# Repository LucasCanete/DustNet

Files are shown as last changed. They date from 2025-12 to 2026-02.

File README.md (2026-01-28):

# DustNet
Dust Measuring Station - Hochschule Osnabrück/Metropolia University

## Board Features

- Dual-socket for Polverine and DFR1117 (mutually excl.)
- LiPo Protection Circuit
- 5V Power
- MPPT for charging
- USB-C for charging
- BME690 footprint (I2C)
- BMV080 connector (I2C)
- SPS30 connector (I2C)

## BOM

TBD

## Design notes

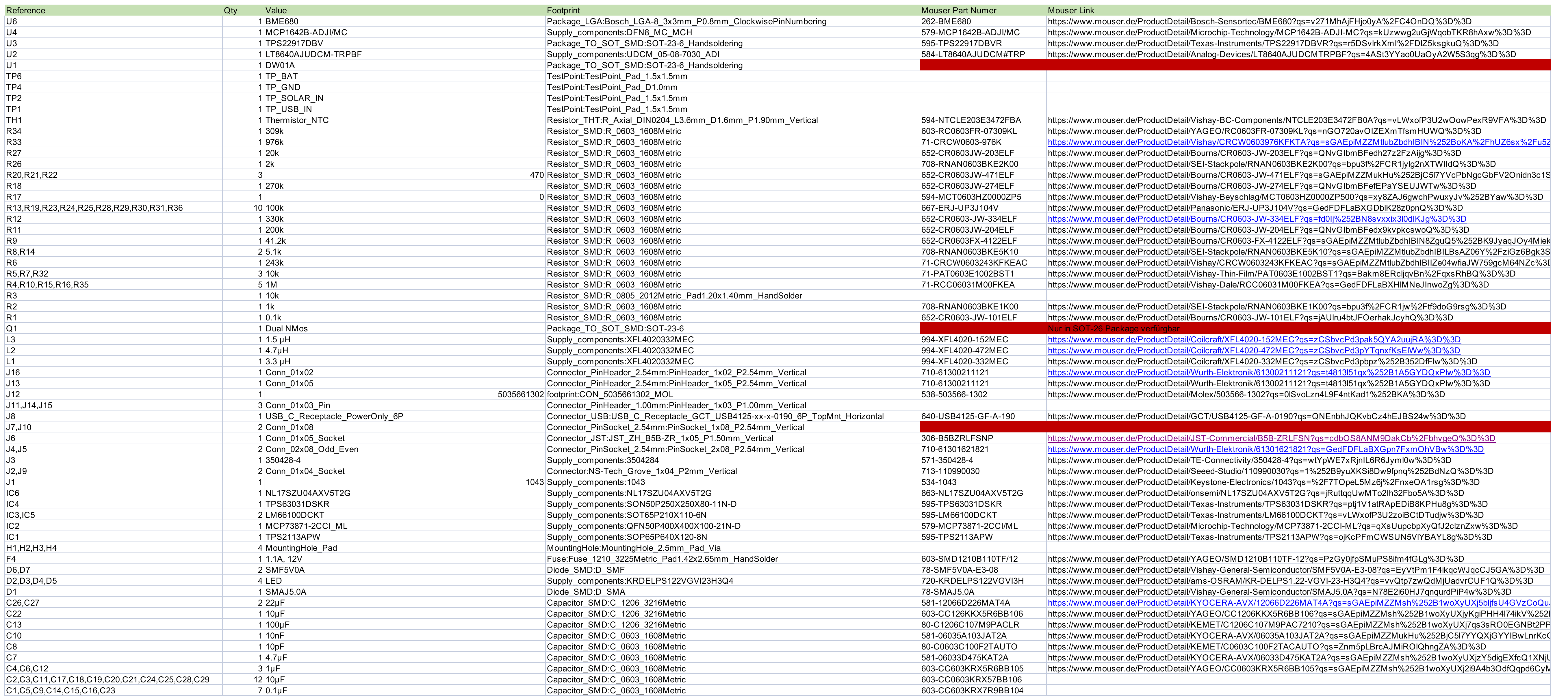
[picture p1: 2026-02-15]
isd-board_polverine_v2/isd-board_polverine.png

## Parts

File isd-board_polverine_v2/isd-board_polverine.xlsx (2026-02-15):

Reference | Qty | Value | Footprint | Mouser Part Numer | Mouser Link
U6 | 1 | BME680 | Package_LGA:Bosch_LGA-8_3x3mm_P0.8mm_ClockwisePinNumbering | 262-BME680 | https://www.mouser.de/ProductDetail/Bosch-Sensortec/BME680?qs=v271MhAjFHjo0yA%2FC4OnDQ%3D%3D
U4 | 1 | MCP1642B-ADJI/MC | Supply_components:DFN8_MC_MCH | 579-MCP1642B-ADJI/MC | https://www.mouser.de/ProductDetail/Microchip-Technology/MCP1642B-ADJI-MC?qs=kUzwwg2uGjWqobTKR8hAxw%3D%3D
U3 | 1 | TPS22917DBV | Package_TO_SOT_SMD:SOT-23-6_Handsoldering | 595-TPS22917DBVR | https://www.mouser.de/ProductDetail/Texas-Instruments/TPS22917DBVR?qs=r5DSvlrkXmI%2FDlZ5ksgkuQ%3D%3D
U2 | 1 | LT8640AJUDCM-TRPBF | Supply_components:UDCM_05-08-7030_ADI | 584-LT8640AJUDCM#TRP | https://www.mouser.de/ProductDetail/Analog-Devices/LT8640AJUDCMTRPBF?qs=4ASt3YYao0UaOyA2W5S3qg%3D%3D
U1 | 1 | DW01A | Package_TO_SOT_SMD:SOT-23-6_Handsoldering
TP6 | 1 | TP_BAT | TestPoint:TestPoint_Pad_1.5x1.5mm
TP4 | 1 | TP_GND | TestPoint:TestPoint_Pad_D1.0mm
TP2 | 1 | TP_SOLAR_IN | TestPoint:TestPoint_Pad_1.5x1.5mm
TP1 | 1 | TP_USB_IN | TestPoint:TestPoint_Pad_1.5x1.5mm
TH1 | 1 | Thermistor_NTC | Resistor_THT:R_Axial_DIN0204_L3.6mm_D1.6mm_P1.90mm_Vertical | 594-NTCLE203E3472FBA | https://www.mouser.de/ProductDetail/Vishay-BC-Components/NTCLE203E3472FB0A?qs=vLWxofP3U2wOowPexR9VFA%3D%3D
R34 | 1 | 309k | Resistor_SMD:R_0603_1608Metric | 603-RC0603FR-07309KL | https://www.mouser.de/ProductDetail/YAGEO/RC0603FR-07309KL?qs=nGO720avOIZEXmTfsmHUWQ%3D%3D
R33 | 1 | 976k | Resistor_SMD:R_0603_1608Metric | 71-CRCW0603-976K | https://www.mouser.de/ProductDetail/Vishay/CRCW0603976KFKTA
R27 | 1 | 20k | Resistor_SMD:R_0603_1608Metric | 652-CR0603JW-203ELF | https://www.mouser.de/ProductDetail/Bourns/CR0603-JW-203ELF?qs=QNvGIbmBFedh27z2FzAijg%3D%3D
R26 | 1 | 2k | Resistor_SMD:R_0603_1608Metric | 708-RNAN0603BKE2K00 | https://www.mouser.de/ProductDetail/SEI-Stackpole/RNAN0603BKE2K00?qs=bpu3f%2FCR1jylg2nXTWIIdQ%3D%3D
R20,R21,R22 | 3 | 470 | Resistor_SMD:R_0603_1608Metric | 652-CR0603JW-471ELF | https://www.mouser.de/ProductDetail/Bourns/CR0603-JW-471ELF
R18 | 1 | 270k | Resistor_SMD:R_0603_1608Metric | 652-CR0603JW-274ELF | https://www.mouser.de/ProductDetail/Bourns/CR0603-JW-274ELF?qs=QNvGIbmBFefEPaYSEUJWTw%3D%3D
R17 | 1 | 0 | Resistor_SMD:R_0603_1608Metric | 594-MCT0603HZ0000ZP5 | https://www.mouser.de/ProductDetail/Vishay-Beyschlag/MCT0603HZ0000ZP500?qs=xy8ZAJ6gwchPwuxyJv%252BYaw%3D%3D
R13,R19,R23,R24,R25,R28,R29,R30,R31,R36 | 10 | 100k | Resistor_SMD:R_0603_1608Metric | 667-ERJ-UP3J104V | https://www.mouser.de/ProductDetail/Panasonic/ERJ-UP3J104V?qs=GedFDFLaBXGDblK28z0pnQ%3D%3D
R12 | 1 | 330k | Resistor_SMD:R_0603_1608Metric | 652-CR0603-JW-334ELF | https://www.mouser.de/ProductDetail/Bourns/CR0603-JW-334ELF?qs=fd0Ij%252BN8svxxix3l0dIKJg%3D%3D
R11 | 1 | 200k | Resistor_SMD:R_0603_1608Metric | 652-CR0603JW-204ELF | https://www.mouser.de/ProductDetail/Bourns/CR0603-JW-204ELF?qs=QNvGIbmBFedx9kvpkcswoQ%3D%3D
R9 | 1 | 41.2k | Resistor_SMD:R_0603_1608Metric | 652-CR0603FX-4122ELF | https://www.mouser.de/ProductDetail/Bourns/CR0603-FX-4122ELF
R8,R14 | 2 | 5.1k | Resistor_SMD:R_0603_1608Metric | 708-RNAN0603BKE5K10 | https://www.mouser.de/ProductDetail/SEI-Stackpole/RNAN0603BKE5K10
R6 | 1 | 243k | Resistor_SMD:R_0603_1608Metric | 71-CRCW0603243KFKEAC | https://www.mouser.de/ProductDetail/Vishay/CRCW0603243KFKEAC?qs=sGAEpiMZZMtlubZbdhIBIIZe04wfiaJW759gcM64NZc%3D
R5,R7,R32 | 3 | 10k | Resistor_SMD:R_0603_1608Metric | 71-PAT0603E1002BST1 | https://www.mouser.de/ProductDetail/Vishay-Thin-Film/PAT0603E1002BST1?qs=Bakm8ERcljqvBn%2FqxsRhBQ%3D%3D
R4,R10,R15,R16,R35 | 5 | 1M | Resistor_SMD:R_0603_1608Metric | 71-RCC06031M00FKEA | https://www.mouser.de/ProductDetail/Vishay-Dale/RCC06031M00FKEA?qs=GedFDFLaBXHlMNeJInwoZg%3D%3D
R3 | 1 | 10k | Resistor_SMD:R_0805_2012Metric_Pad1.20x1.40mm_HandSolder
R2 | 1 | 1k | Resistor_SMD:R_0603_1608Metric | 708-RNAN0603BKE1K00 | https://www.mouser.de/ProductDetail/SEI-Stackpole/RNAN0603BKE1K00?qs=bpu3f%2FCR1jw%2Ftf9doG9rsg%3D%3D
R1 | 1 | 0.1k | Resistor_SMD:R_0603_1608Metric | 652-CR0603-JW-101ELF | https://www.mouser.de/ProductDetail/Bourns/CR0603-JW-101ELF?qs=jAUlru4btJFOerhakJcyhQ%3D%3D
Q1 | 1 | Dual NMos | Package_TO_SOT_SMD:SOT-23-6 |  | Nur in SOT-26 Package verfürgbar
L3 | 1 | 1.5 µH | Supply_components:XFL4020332MEC | 994-XFL4020-152MEC | https://www.mouser.de/ProductDetail/Coilcraft/XFL4020-152MEC?qs=zCSbvcPd3pak5QYA2uujRA%3D%3D
L2 | 1 | 4.7µH | Supply_components:XFL4020332MEC | 994-XFL4020-472MEC | https://www.mouser.de/ProductDetail/Coilcraft/XFL4020-472MEC?qs=zCSbvcPd3pYTqnxfKsElWw%3D%3D
L1 | 1 | 3.3 µH | Supply_components:XFL4020332MEC | 994-XFL4020-332MEC | https://www.mouser.de/ProductDetail/Coilcraft/XFL4020-332MEC?qs=zCSbvcPd3pbpz%252B352DfFlw%3D%3D
J16 | 1 | Conn_01x02 | Connector_PinHeader_2.54mm:PinHeader_1x02_P2.54mm_Vertical | 710-61300211121 | https://www.mouser.de/ProductDetail/Wurth-Elektronik/61300211121?qs=t4813l51qx%252B1A5GYDQxPlw%3D%3D
J13 | 1 | Conn_01x05 | Connector_PinHeader_2.54mm:PinHeader_1x05_P2.54mm_Vertical | 710-61300211121 | https://www.mouser.de/ProductDetail/Wurth-Elektronik/61300211121?qs=t4813l51qx%252B1A5GYDQxPlw%3D%3D
J12 | 1 | 5035661302 | footprint:CON_5035661302_MOL | 538-503566-1302 | https://www.mouser.de/ProductDetail/Molex/503566-1302?qs=0lSvoLzn4L9F4ntKad1%252BKA%3D%3D
J11,J14,J15 | 3 | Conn_01x03_Pin | Connector_PinHeader_1.00mm:PinHeader_1x03_P1.00mm_Vertical
J8 | 1 | USB_C_Receptacle_PowerOnly_6P | Connector_USB:USB_C_Receptacle_GCT_USB4125-xx-x-0190_6P_TopMnt_Horizontal | 640-USB4125-GF-A-190 | https://www.mouser.de/ProductDetail/GCT/USB4125-GF-A-0190?qs=QNEnbhJQKvbCz4hEJBS24w%3D%3D
J7,J10 | 2 | Conn_01x08 | Connector_PinSocket_2.54mm:PinSocket_1x08_P2.54mm_Vertical
J6 | 1 | Conn_01x05_Socket | Connector_JST:JST_ZH_B5B-ZR_1x05_P1.50mm_Vertical | 306-B5BZRLFSNP | https://www.mouser.de/ProductDetail/JST-Commercial/B5B-ZRLFSN?qs=cdbOS8ANM9DakCb%2FbhvgeQ%3D%3D
J4,J5 | 2 | Conn_02x08_Odd_Even | Connector_PinSocket_2.54mm:PinSocket_2x08_P2.54mm_Vertical | 710-61301621821 | https://www.mouser.de/ProductDetail/Wurth-Elektronik/61301621821?qs=GedFDFLaBXGpn7FxmOhVBw%3D%3D
J3 | 1 | 350428-4 | Supply_components:3504284 | 571-350428-4 | https://www.mouser.de/ProductDetail/TE-Connectivity/350428-4?qs=wtYpWE7xRjnIL6R6Jyml0w%3D%3D
J2,J9 | 2 | Conn_01x04_Socket | Connector:NS-Tech_Grove_1x04_P2mm_Vertical | 713-110990030 | https://www.mouser.de/ProductDetail/Seeed-Studio/110990030?qs=1%252B9yuXKSi8Dw9fpnq%252BdNzQ%3D%3D
J1 | 1 | 1043 | Supply_components:1043 | 534-1043 | https://www.mouser.de/ProductDetail/Keystone-Electronics/1043?qs=%2F7TOpeL5Mz6j%2FnxeOA1rsg%3D%3D
IC6 | 1 | NL17SZU04AXV5T2G | Supply_components:NL17SZU04AXV5T2G | 863-NL17SZU04AXV5T2G | https://www.mouser.de/ProductDetail/onsemi/NL17SZU04AXV5T2G?qs=jRuttqqUwMTo2Ih32Fbo5A%3D%3D
IC4 | 1 | TPS63031DSKR | Supply_components:SON50P250X250X80-11N-D | 595-TPS63031DSKR | https://www.mouser.de/ProductDetail/Texas-Instruments/TPS63031DSKR?qs=ptj1V1atRApEDiB8KPHu8g%3D%3D
IC3,IC5 | 2 | LM66100DCKT | Supply_components:SOT65P210X110-6N | 595-LM66100DCKT | https://www.mouser.de/ProductDetail/Texas-Instruments/LM66100DCKT?qs=vLWxofP3U2zoiBCtDTudjw%3D%3D
IC2 | 1 | MCP73871-2CCI_ML | Supply_components:QFN50P400X400X100-21N-D | 579-MCP73871-2CCI/ML | https://www.mouser.de/ProductDetail/Microchip-Technology/MCP73871-2CCI-ML?qs=qXsUupcbpXyQfJ2clznZxw%3D%3D
IC1 | 1 | TPS2113APW | Supply_components:SOP65P640X120-8N | 595-TPS2113APW | https://www.mouser.de/ProductDetail/Texas-Instruments/TPS2113APW?qs=ojKcPFmCWSUN5VlYBAYL8g%3D%3D
H1,H2,H3,H4 | 4 | MountingHole_Pad | MountingHole:MountingHole_2.5mm_Pad_Via
F4 | 1 | 1.1A, 12V | Fuse:Fuse_1210_3225Metric_Pad1.42x2.65mm_HandSolder | 603-SMD1210B110TF/12 | https://www.mouser.de/ProductDetail/YAGEO/SMD1210B110TF-12?qs=PzGy0jfpSMuPS8ifm4fGLg%3D%3D
D6,D7 | 2 | SMF5V0A | Diode_SMD:D_SMF | 78-SMF5V0A-E3-08 | https://www.mouser.de/ProductDetail/Vishay-General-Semiconductor/SMF5V0A-E3-08?qs=EyVtPm1F4ikqcWJqcCJ5GA%3D%3D
D2,D3,D4,D5 | 4 | LED | Supply_components:KRDELPS122VGVI23H3Q4 | 720-KRDELPS122VGVI3H | https://www.mouser.de/ProductDetail/ams-OSRAM/KR-DELPS1.22-VGVI-23-H3Q4?qs=vvQtp7zwQdMjUadvrCUF1Q%3D%3D
D1 | 1 | SMAJ5.0A | Diode_SMD:D_SMA | 78-SMAJ5.0A | https://www.mouser.de/ProductDetail/Vishay-General-Semiconductor/SMAJ5.0A?qs=N78E2i60HJ7qnqurdPiP4w%3D%3D
C26,C27 | 2 | 22µF | Capacitor_SMD:C_1206_3216Metric | 581-12066D226MAT4A | https://www.mouser.de/ProductDetail/KYOCERA-AVX/12066D226MAT4A
C22 | 1 | 10µF | Capacitor_SMD:C_1206_3216Metric | 603-CC126KKX5R6BB106 | https://www.mouser.de/ProductDetail/YAGEO/CC1206KKX5R6BB106
C13 | 1 | 100µF | Capacitor_SMD:C_1206_3216Metric | 80-C1206C107M9PACLR | https://www.mouser.de/ProductDetail/KEMET/C1206C107M9PAC7210
C10 | 1 | 10nF | Capacitor_SMD:C_0603_1608Metric | 581-06035A103JAT2A | https://www.mouser.de/ProductDetail/KYOCERA-AVX/06035A103JAT2A
C8 | 1 | 10pF | Capacitor_SMD:C_0603_1608Metric | 80-C0603C100F2TAUTO | https://www.mouser.de/ProductDetail/KEMET/C0603C100F2TACAUTO?qs=Znm5pLBrcAJMiROlQhngZA%3D%3D
C7 | 1 | 4.7µF | Capacitor_SMD:C_0603_1608Metric | 581-06033D475KAT2A | https://www.mouser.de/ProductDetail/KYOCERA-AVX/06033D475KAT2A
C4,C6,C12 | 3 | 1µF | Capacitor_SMD:C_0603_1608Metric | 603-CC603KRX5R6BB105 | https://www.mouser.de/ProductDetail/YAGEO/CC0603KRX5R6BB105
C2,C3,C11,C17,C18,C19,C20,C21,C24,C25,C28,C29 | 12 | 10µF | Capacitor_SMD:C_0603_1608Metric | 603-CC0603KRX57BB106
C1,C5,C9,C14,C15,C16,C23 | 7 | 0.1µF | Capacitor_SMD:C_0603_1608Metric | 603-CC603KRX7R9BB104

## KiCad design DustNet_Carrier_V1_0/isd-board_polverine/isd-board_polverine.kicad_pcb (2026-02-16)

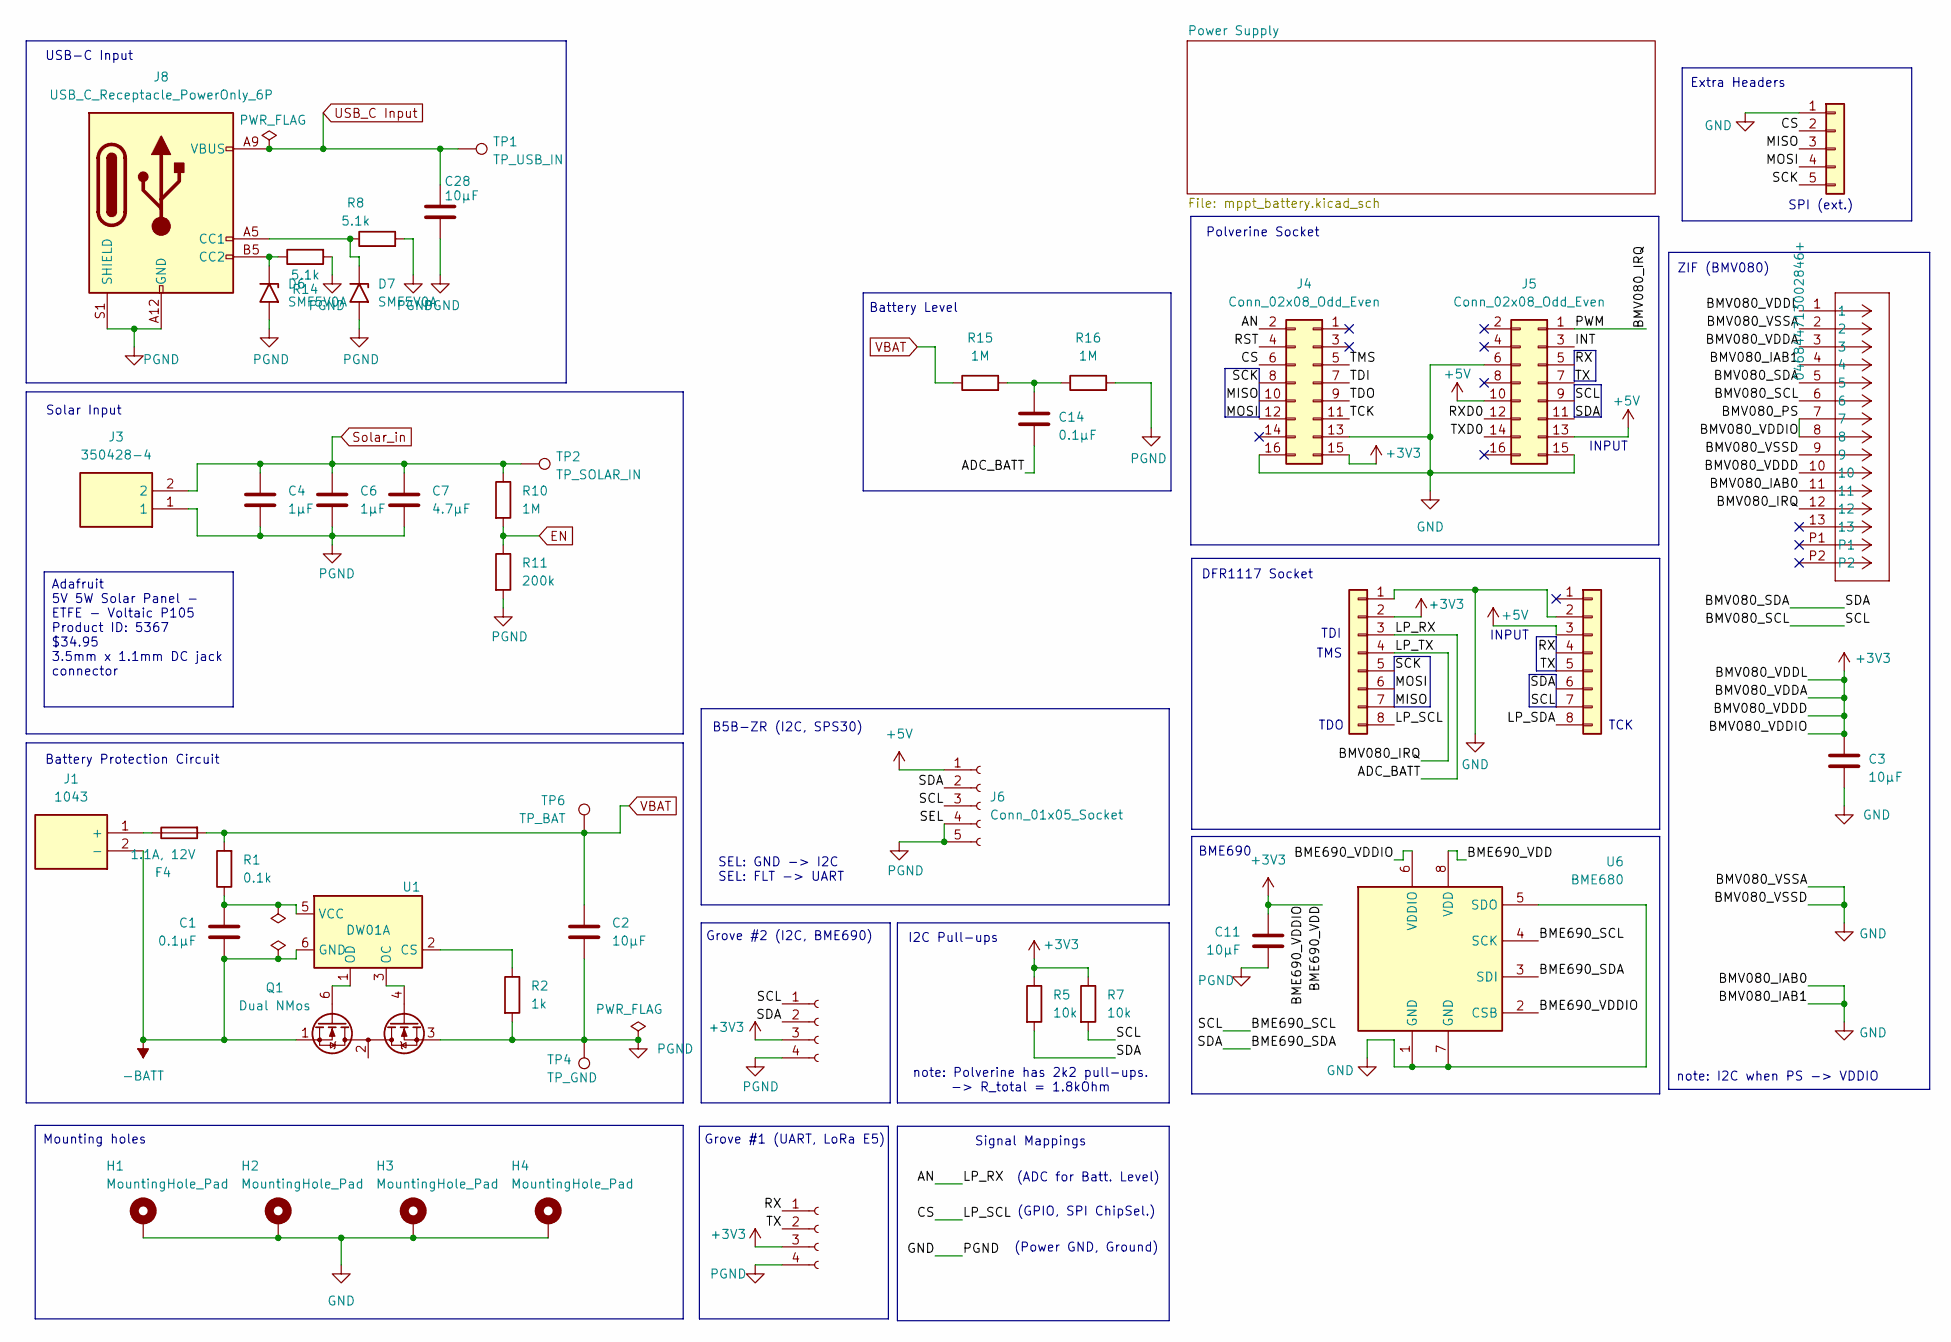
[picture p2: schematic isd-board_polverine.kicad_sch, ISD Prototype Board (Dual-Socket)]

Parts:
C1, C14: 0.1µF; C_0603_1608Metric; MPN 399-C0805C104K5RACTUCT-ND
C2, C3, C11: 10µF; C_0603_1608Metric; MPN GRM21BR61E106KA73K
C4, C6: 1µF; C_0603_1608Metric
C7: 4.7µF; C_0603_1608Metric
C28: 10µF; C_0603_1608Metric
D6, D7: SMF5V0A; D_SMF
F4: 1.1A, 12V; Fuse_1210_3225Metric_Pad1.42x2.65mm_HandSolder; MPN SMD1210B110TF
H1, H2, H3, H4: MountingHole_Pad; MountingHole_2.5mm_Pad_Via; MPN none
J1: 1043; Mouser Part Number 534-1043
J2, J9: Conn_01x04_Socket; NS-Tech_Grove_1x04_P2mm_Vertical; MPN 1597-1082-ND
J3: 350428-4; 3504284; Mouser Part Number 571-350428-4
J4, J5: Conn_02x08_Odd_Even; PinSocket_2x08_P2.54mm_Vertical; MPN 732-61301621821-ND
J6: Conn_01x05_Socket; JST_ZH_B5B-ZR_1x05_P1.50mm_Vertical; MPN B5B-ZR
J7, J10: Conn_01x08; PinSocket_1x08_P2.54mm_Vertical; MPN PPTC081LFBN-RC
J8: USB_C_Receptacle_PowerOnly_6P; USB_C_Receptacle_GCT_USB4125-xx-x-0190_6P_TopMnt_Horizontal; MPN USB4125-GF-A
J12: 5035661302; CON_5035661302_MOL; MPN 046844713002846+
J13: Conn_01x05; PinHeader_1x05_P2.54mm_Vertical; MPN ???
Q1: Dual NMos; SOT-23-6; MPN DMG9926UDMDICT-ND
R1: 0.1k; R_0603_1608Metric; MPN 541-100CCT-ND
R2: 1k; R_0603_1608Metric; MPN 10-ERJ-HP6J102VCT-ND
R5, R7: 10k; R_0603_1608Metric; MPN 541-4163-1-ND
R8, R14: 5.1k; R_0603_1608Metric; MPN 311-5.1KARCT-ND
R10: 1M; R_0603_1608Metric
R11: 200k; R_0603_1608Metric
R15, R16: 1M; R_0603_1608Metric; MPN 408-RG2012P-105-B-T5CT-ND
TP1: TP_USB_IN; TestPoint_Pad_1.5x1.5mm; MPN none
TP2: TP_SOLAR_IN; TestPoint_Pad_1.5x1.5mm; MPN none
TP4: TP_GND; TestPoint_Pad_D1.0mm; MPN none
TP6: TP_BAT; TestPoint_Pad_1.5x1.5mm; MPN none
U1: DW01A; SOT-23-6_Handsoldering; MPN DW01A
U6: BME680; Bosch_LGA-8_3x3mm_P0.8mm_ClockwisePinNumbering; MPN BME690

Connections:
+3V3: C3.1, C11.1, J2.3, J4.15, J9.3, J10.2, J12.1, J12.3, J12.7, J12.8, J12.10, R5.1, R7.1, U6.2 (CSB), U6.6 (VDDIO), U6.8 (VDD); also elsewhere on the board
+5V: J5.10, J5.13, J6.1, J7.3; also elsewhere on the board
-BATT: C1.2, J1.2 (-), Q1.1 (D1), U1.6 (GND)
/ADC_BATT: C14.2, J4.2, J10.3
/BME690_SCL: J2.1, J5.9, J6.3, J7.7, J12.6, R7.2, U6.4 (SCK)
/BME690_SDA: J2.2, J5.11, J6.2, J7.6, J12.5, R5.2, U6.3 (SDI)
/BMV080_IRQ: J5.1, J10.4, J12.12
/CS: J4.6, J10.8, J13.2
/INT: J5.3
/LP_SDA: J7.8
/MISO: J4.10, J10.7, J13.3
/MOSI: J4.12, J10.6, J13.4
/RST: J4.4
/RX: J5.5, J7.4, J9.1
/RXD0: J5.12
/SCK: J4.8, J10.5, J13.5
/TCK: J4.11
/TDI: J4.7
/TDO: J4.9
/TMS: J4.5
/TX: J5.7, J7.5, J9.2
/TXD0: J5.14
EN: R10.2, R11.1; also elsewhere on the board
unnamed: C14.1, R15.2, R16.1
unnamed: D6.1 (A1), J8.B5 (CC2), R14.1
unnamed: D7.1 (A1), J8.A5 (CC1), R8.1
unnamed: F4.1, J1.1 (+)
unnamed: Q1.6 (G1), U1.1 (OD)
unnamed: Q1.4 (G2), U1.3 (OC)
unnamed: Q1.2 (S1/D2), Q1.5 (S1/D2)
unnamed: R2.1, U1.2 (CS)
unnamed: C1.1, R1.1, U1.5 (VCC)
Solar_in: C4.1, C6.1, C7.1, J3.2, R10.1, TP2.1; also elsewhere on the board
USB_C Input: C28.1, J8.A9 (VBUS), J8.B9 (VBUS), TP1.1; also elsewhere on the board
VBAT: C2.1, F4.2, R1.2, R15.1, TP6.1; also elsewhere on the board

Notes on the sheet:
INPUT
B5B-ZR (I2C, SPS30)
Polverine Socket
TDO
I2C Pull-ups
Battery Level
note: Polverine has 2k2 pull-ups. -> R_total = 1.8kOhm
Solar Input
DFR1117 Socket
Mounting holes
TDI
BME690
(GPIO, SPI ChipSel.)
TCK
Extra Headers
(ADC for Batt. Level)
(Power GND, Ground)
USB-C Input
ZIF (BMV080)
Grove #1 (UART, LoRa E5)
SPI (ext.)
note: I2C when PS -> VDDIO
Battery Protection Circuit
Signal Mappings
TMS
SEL: GND -> I2C SEL: FLT -> UART
Grove #2 (I2C, BME690)
Adafruit 5V 5W Solar Panel - ETFE - Voltaic P105 Product ID: 5367 $34.95 3.5mm x 1.1mm DC jack connector

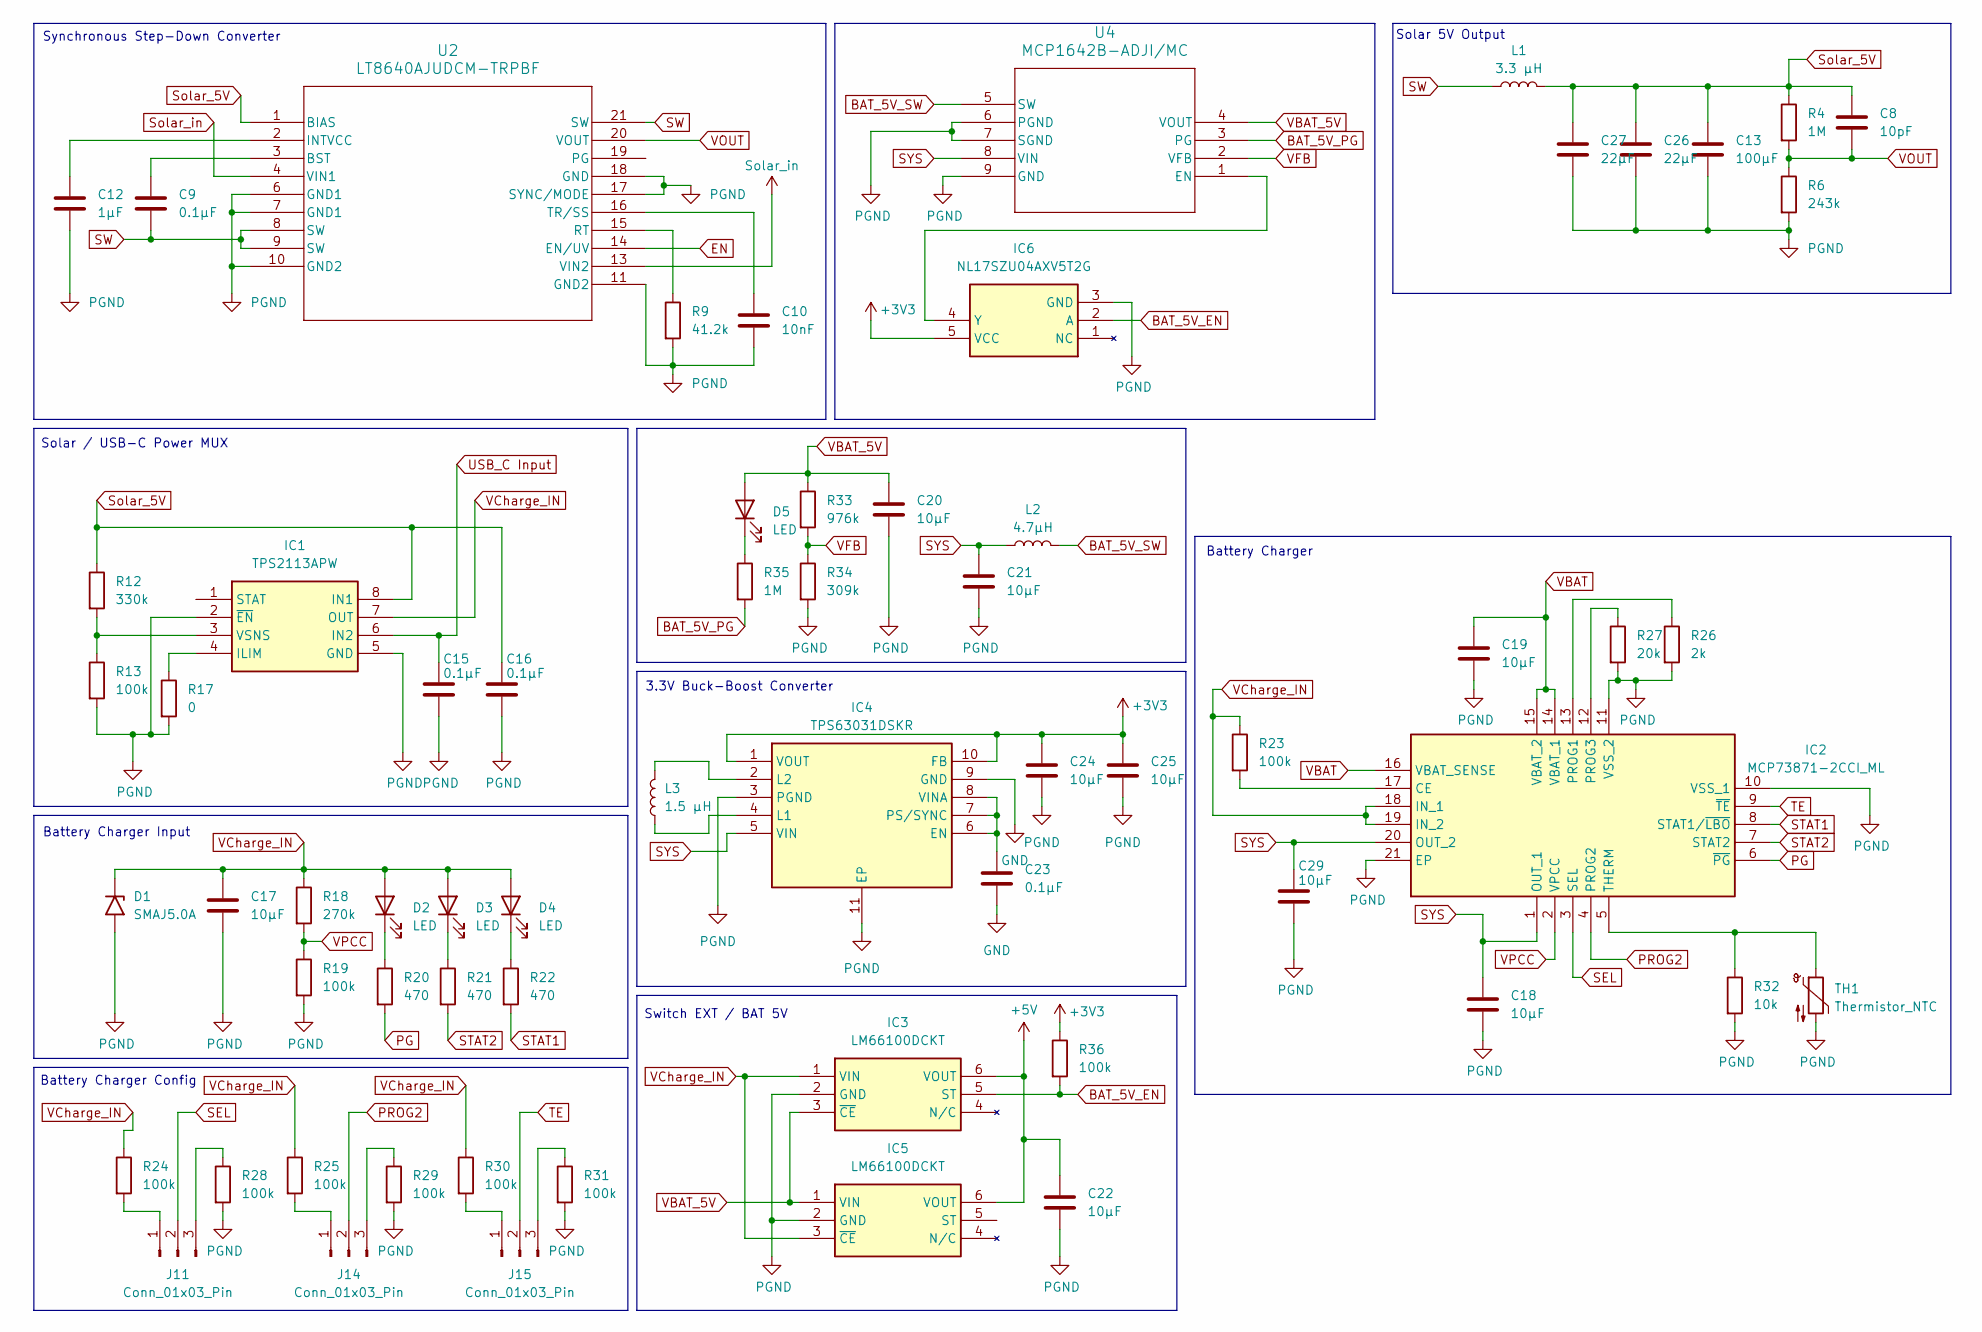
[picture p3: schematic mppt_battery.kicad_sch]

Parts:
C8: 10pF; C_0603_1608Metric
C9, C15, C16, C23: 0.1µF; C_0603_1608Metric
C10: 10nF; C_0603_1608Metric
C12: 1µF; C_0603_1608Metric
C13: 100µF; C_1206_3216Metric
C17, C18, C19, C20, C21, C22, C24, C25, C29: 10µF; C_0603_1608Metric
C26, C27: 22µF; C_1206_3216Metric
D1: SMAJ5.0A; D_SMA
D2, D3, D4, D5: LED; KRDELPS122VGVI23H3Q4
IC1: TPS2113APW; SOP65P640X120-8N; Mouser Part Number 595-TPS2113APW
IC2: MCP73871-2CCI_ML; QFN50P400X400X100-21N-D; Mouser Part Number 579-MCP73871-2CCI/ML
IC3, IC5: LM66100DCKT; SOT65P210X110-6N; Mouser Part Number 595-LM66100DCKT
IC4: TPS63031DSKR; SON50P250X250X80-11N-D; Mouser Part Number 595-TPS63031DSKR
IC6: NL17SZU04AXV5T2G; Manufacturer_Part_Number NL17SZU04AXV5T2G
J11, J14, J15: Conn_01x03_Pin; PinHeader_1x03_P2.54mm_Vertical
L1: 3.3 µH; XFL4020332MEC
L2: 4.7µH; XFL4020332MEC
L3: 1.5 µH; XFL4020332MEC
R4, R35: 1M; R_0603_1608Metric
R6: 243k; R_0603_1608Metric
R9: 41.2k; R_0603_1608Metric
R12: 330k; R_0603_1608Metric
R13, R19, R23, R24, R25, R28, R29, R30, R31, R36: 100k; R_0603_1608Metric
R17: 0; R_0603_1608Metric
R18: 270k; R_0603_1608Metric
R20, R21, R22: 470; R_0603_1608Metric
R26: 2k; R_0603_1608Metric
R27: 20k; R_0603_1608Metric
R32: 10k; R_0603_1608Metric
R33: 976k; R_0603_1608Metric
R34: 309k; R_0603_1608Metric
TH1: Thermistor_NTC; R_Axial_DIN0204_L3.6mm_D1.6mm_P1.90mm_Vertical
U2: LT8640AJUDCM-TRPBF; UDCM_05-08-7030_ADI
U4: MCP1642B-ADJI/MC; DFN8_MC_MCH

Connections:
+3V3: C24.1, C25.1, IC4.1 (VOUT), IC4.10 (FB), IC6.5 (VCC), R36.1; also elsewhere on the board
+5V: C22.1, IC3.6 (VOUT), IC5.6 (VOUT); also elsewhere on the board
BAT_5V_EN: IC3.5 (ST), IC6.2 (A), R36.2
BAT_5V_PG: R35.2, U4.3 (PG)
BAT_5V_SW: L2.2, U4.5 (SW)
EN: U2.14 (EN/UV); also elsewhere on the board
unnamed: D2.1 (K), R20.1
unnamed: D3.1 (K), R21.1
unnamed: D4.1 (K), R22.1
unnamed: D5.1 (K), R35.1
unnamed: IC1.4 (ILIM), R17.1
unnamed: IC1.3 (VSNS), R12.2, R13.1
unnamed: IC2.17 (CE), R23.2
unnamed: IC2.13 (PROG1), R26.1
unnamed: IC2.12 (PROG3), R27.1
unnamed: IC2.5 (THERM), R32.1, TH1.1
unnamed: C23.1, IC4.6 (EN), IC4.7 (PS/SYNC), IC4.8 (VINA)
unnamed: IC4.4 (L1), L3.1
unnamed: IC4.2 (L2), L3.2
unnamed: IC6.4 (Y), U4.1 (EN)
unnamed: J11.1, R24.2
unnamed: J11.3, R28.1
unnamed: J14.1, R25.2
unnamed: J14.3, R29.1
unnamed: J15.1, R30.2
unnamed: J15.3, R31.1
unnamed: C9.1, U2.3 (BST)
unnamed: C12.1, U2.2 (INTVCC)
unnamed: R9.1, U2.15 (RT)
unnamed: C10.1, U2.16 (TR/SS)
PG: IC2.6 (~PG), R20.2
PROG2: IC2.4 (PROG2), J14.2
SEL: IC2.3 (SEL), J11.2
STAT1: IC2.8 (STAT1/~LBO), R22.2
STAT2: IC2.7 (STAT2), R21.2
SW: C9.2, L1.1, U2.8 (SW), U2.9 (SW), U2.21 (SW)
SYS: C18.1, C21.1, C29.1, IC2.1 (OUT_1), IC2.20 (OUT_2), IC4.5 (VIN), L2.1, U4.8 (VIN)
Solar_5V: C8.1, C13.1, C16.1, C26.1, C27.1, IC1.8 (IN1), L1.2, R4.1, R12.1, U2.1 (BIAS)
Solar_in: U2.4 (VIN1), U2.13 (VIN2); also elsewhere on the board
TE: IC2.9 (~TE), J15.2
USB_C Input: C15.1, IC1.6 (IN2); also elsewhere on the board
VBAT: C19.1, IC2.14 (VBAT_1), IC2.15 (VBAT_2), IC2.16 (VBAT_SENSE); also elsewhere on the board
VBAT_5V: C20.1, D5.2 (A), IC3.3 (~CE), IC5.1 (VIN), R33.1, U4.4 (VOUT)
VCharge_IN: C17.1, D1.1 (A1), D2.2 (A), D3.2 (A), D4.2 (A), IC1.7 (OUT), IC2.18 (IN_1), IC2.19 (IN_2), IC3.1 (VIN), IC5.3 (~CE), R18.1, R23.1, R24.1, R25.1, R30.1
VFB: R33.2, R34.1, U4.2 (VFB)
VOUT: C8.2, R4.2, R6.1, U2.20 (VOUT)
VPCC: IC2.2 (VPCC), R18.2, R19.1

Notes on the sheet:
Solar 5V Output
3.3V Buck-Boost Converter
Solar / USB-C Power MUX
Battery Charger
Switch EXT / BAT 5V
Synchronous Step-Down Converter
Battery Charger Config
Battery Charger Input

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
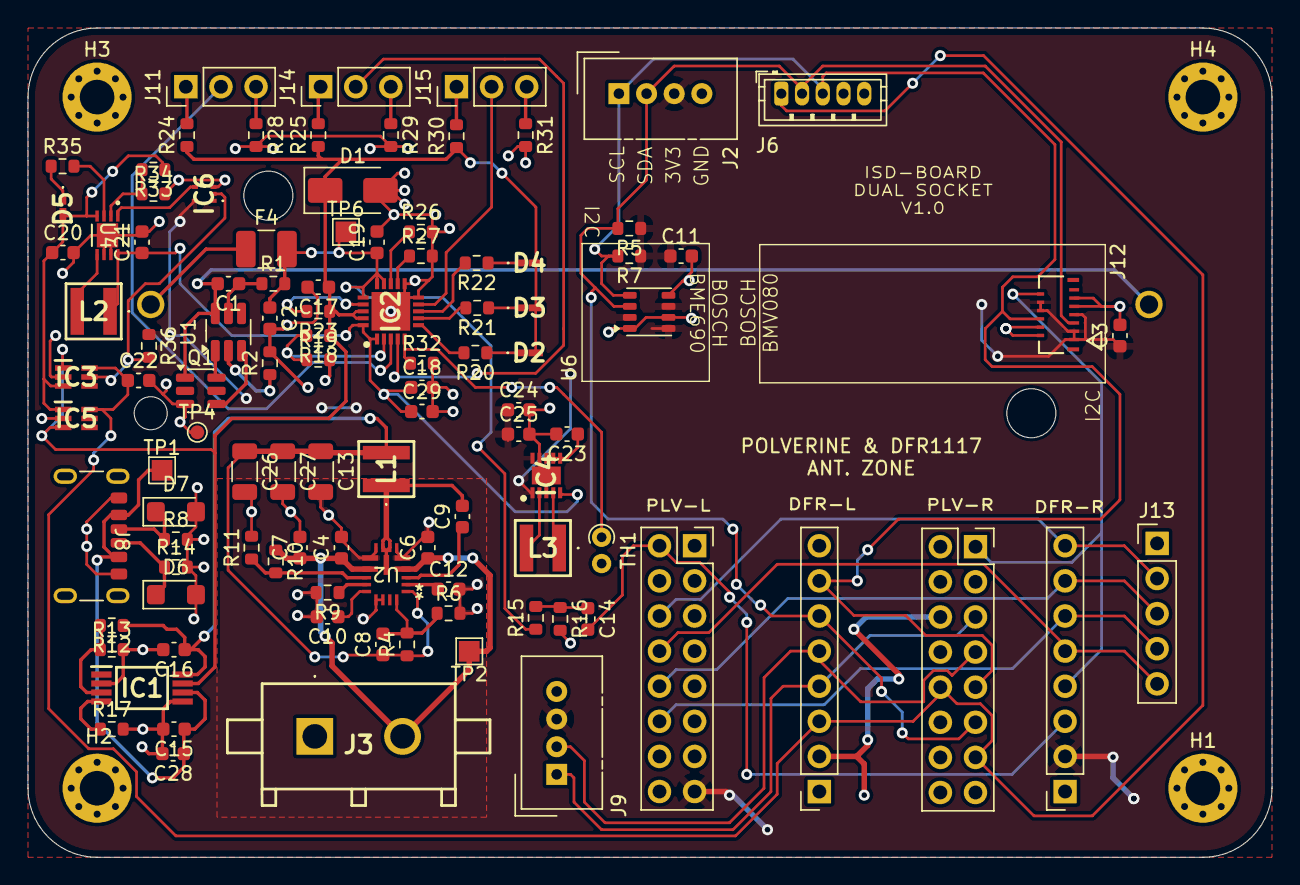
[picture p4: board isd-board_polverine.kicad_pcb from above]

Board: 2 copper layers, 90.0 x 60.0 mm, 109 parts (1 on the bottom side), 68 nets.

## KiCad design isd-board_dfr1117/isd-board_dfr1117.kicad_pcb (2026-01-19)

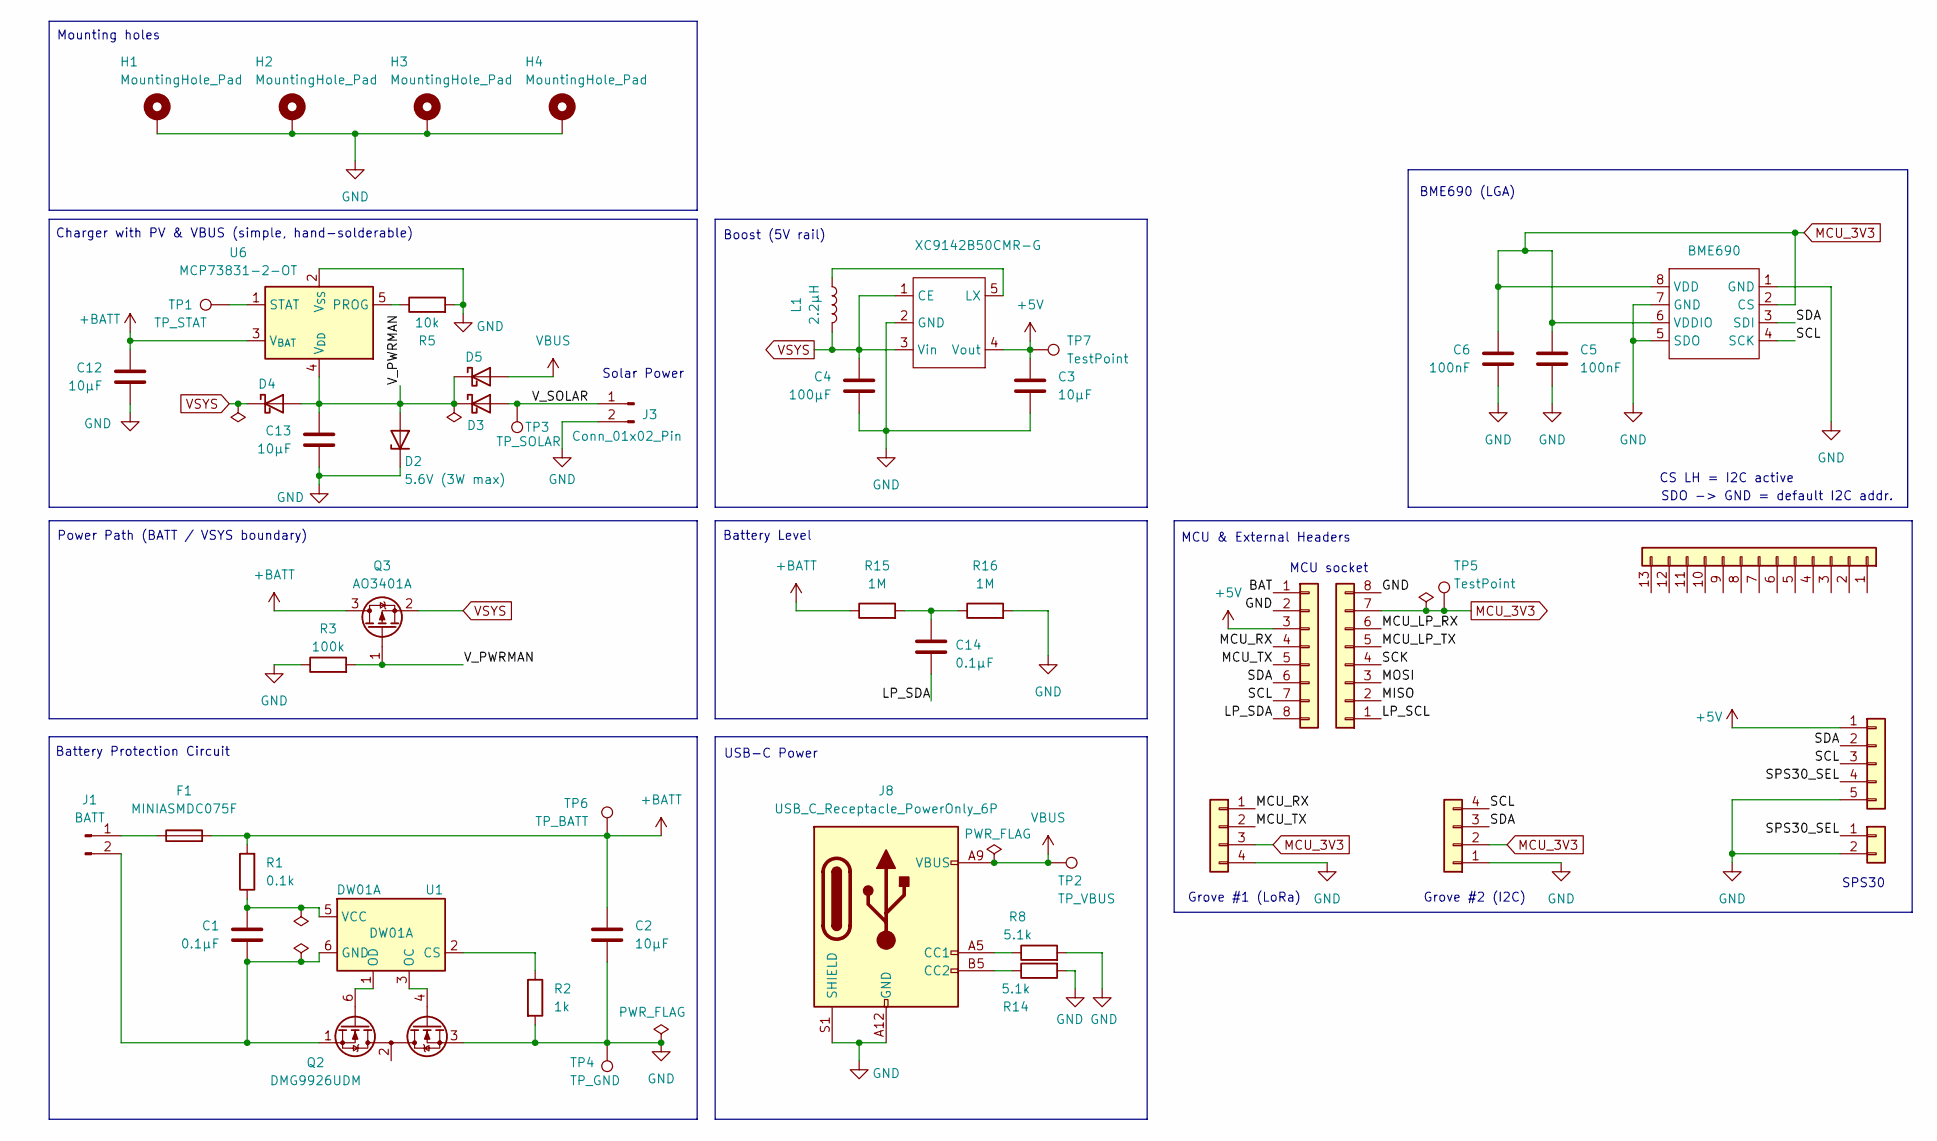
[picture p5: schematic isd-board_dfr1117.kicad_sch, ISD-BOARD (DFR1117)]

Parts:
C1, C14: 0.1µF; C_0805_2012Metric_Pad1.18x1.45mm_HandSolder
C2, C3, C12, C13: 10µF; C_0805_2012Metric_Pad1.18x1.45mm_HandSolder
C4: 100µF; CP_Radial_D5.0mm_P2.50mm
C5, C6: 100nF
D2: 5.6V (3W max); D_SMB_Handsoldering; MPN 1SMB5919BT3G
D3, D4, D5: D_Schottky; D_DO-41_SOD81_P10.16mm_Horizontal
F1: MINIASMDC075F; Fuse_1812_4532Metric_Pad1.30x3.40mm_HandSolder
H1, H2, H3, H4: MountingHole_Pad; MountingHole_2.5mm_Pad_Via
J1: BATT; JST_PH_S2B-PH-K_1x02_P2.00mm_Horizontal
J2, J4: Conn_01x08; PinSocket_1x08_P2.54mm_Vertical
J3: Conn_01x02_Pin; JST_PH_S2B-PH-K_1x02_P2.00mm_Horizontal
J5, J6: Conn_01x04; NS-Tech_Grove_1x04_P2mm_Vertical
J7: Conn_01x05; JST_ZH_B5B-ZR_1x05_P1.50mm_Vertical
J8: USB_C_Receptacle_PowerOnly_6P; USB_C_Receptacle_GCT_USB4125-xx-x-0190_6P_TopMnt_Horizontal
J9: Conn_01x02
J10: Conn_01x13
L1: 2.2µH; L_Bourns-SRN4018; MPN SRN4018-2R2M
Q2: DMG9926UDM; SOT-23-6
Q3: AO3401A; SOT-23_Handsoldering
R1: 0.1k; R_0805_2012Metric_Pad1.20x1.40mm_HandSolder
R2: 1k; R_0805_2012Metric_Pad1.20x1.40mm_HandSolder
R3: 100k; R_0805_2012Metric_Pad1.20x1.40mm_HandSolder
R5: 10k; R_0805_2012Metric_Pad1.20x1.40mm_HandSolder
R8, R14: 5.1k; R_0805_2012Metric_Pad1.20x1.40mm_HandSolder
R15, R16: 1M; R_0805_2012Metric_Pad1.20x1.40mm_HandSolder
TP1: TP_STAT; TestPoint_Pad_D1.0mm
TP2: TP_VBUS; TestPoint_Pad_D1.0mm
TP3: TP_SOLAR; TestPoint_Pad_D1.0mm
TP4: TP_GND; TestPoint_Pad_D1.0mm
TP5, TP7: TestPoint; TestPoint_Pad_D1.0mm
TP6: TP_BATT; TestPoint_Pad_D1.0mm
U1: DW01A; SOT-23-6_Handsoldering
U2: XC9142B50CMR-G; SOT-23-5_HandSoldering
U3: BME690; Bosch_LGA-8_2.5x2.5mm_P0.65mm_ClockwisePinNumbering
U6: MCP73831-2-OT; SOT-23-5_HandSoldering; MPN MCP73831T-2DCI/OT

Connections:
+5V: C3.1, J2.3, J7.1, TP7.1, U2.4 (Vout)
+BATT: C2.1, C12.1, F1.2, Q3.3 (D), R1.2, R15.1, TP6.1, U6.3 (V_{BAT})
/BAT: J2.1
/LP_SCL: J4.1
/LP_SDA: C14.2, J2.8
/MCU_LP_RX: J4.6
/MCU_LP_TX: J4.5
/MCU_RX: J2.4, J5.1
/MCU_TX: J2.5, J5.2
/MISO: J4.2
/MOSI: J4.3
/SCK: J4.4
/SCL: J2.7, J6.4, J7.3, U3.4 (SCK)
/SDA: J2.6, J6.3, J7.2, U3.3 (SDI)
/SPS30_SEL: J7.4, J9.1
/V_PWRMAN: C13.1, D2.2 (A), D3.1 (K), D4.2 (A), D5.1 (K), Q3.1 (G), R3.2, U6.4 (V_{DD})
/V_SOLAR: D3.2 (A), J3.1, TP3.1
GND: C2.2, C3.2, C4.2, C5.2, C6.1, C12.2, C13.2, D2.1 (K), H1.1, H2.1, H3.1, H4.1, J2.2, J3.2, J4.8, J5.4, J6.1, J7.5, J8.A12 (GND), J8.B12 (GND), J8.S1 (SHIELD), J9.2, Q2.3 (S2), R2.2, R3.1, R5.2, R8.2, R14.2, R16.2, TP4.1, U2.2 (GND), U3.1 (GND), U3.5 (SDO), U3.7 (GND), U6.2 (V_{SS})
MCU_3V3: C5.1, C6.2, J4.7, J5.3, J6.2, TP5.1, U3.2 (CS), U3.6 (VDDIO), U3.8 (VDD)
unnamed: C14.1, R15.2, R16.1
unnamed: F1.1, J1.1
unnamed: C1.2, J1.2, Q2.1 (D1), U1.6 (GND)
unnamed: J8.A5 (CC1), R8.1
unnamed: J8.B5 (CC2), R14.1
unnamed: Q2.6 (G1), U1.1 (OD)
unnamed: Q2.4 (G2), U1.3 (OC)
unnamed: Q2.2 (S1/D2), Q2.5 (S1/D2)
unnamed: R2.1, U1.2 (CS)
unnamed: C1.1, R1.1, U1.5 (VCC)
unnamed: L1.2, U2.5 (LX)
unnamed: R5.1, U6.5 (PROG)
unnamed: TP1.1, U6.1 (STAT)
VBUS: D5.2 (A), J8.A9 (VBUS), J8.B9 (VBUS), TP2.1
VSYS: C4.1, D4.1 (K), L1.1, Q3.2 (S), U2.1 (CE), U2.3 (Vin)

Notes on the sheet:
Charger with PV & VBUS (simple, hand-solderable)
Battery Level
Grove #1 (LoRa)
CS LH = I2C active
Mounting holes
MCU & External Headers
MCU socket
SPS30
Solar Power
Boost (5V rail)
SDO -> GND = default I2C addr.
Power Path (BATT / VSYS boundary)
Battery Protection Circuit
Grove #2 (I2C)
USB-C Power
BME690 (LGA)

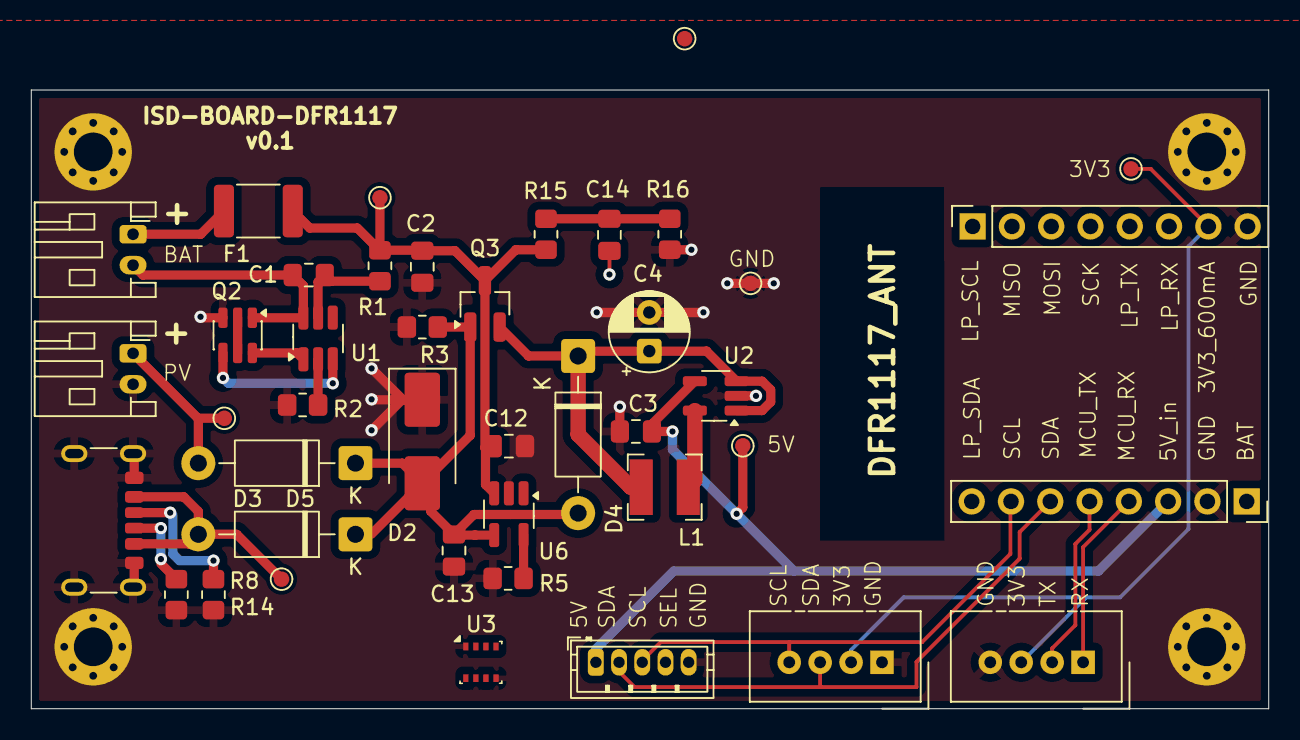
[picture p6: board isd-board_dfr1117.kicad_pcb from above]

Board: 2 copper layers, 80.0 x 40.0 mm, 46 parts (0 on the bottom side), 26 nets.

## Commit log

2025-12-05 add: gitignore (ignore kicad locks, backups)
2025-12-05 add: kicad library tree
2025-12-05 update: README.md (BOM, targets)
2025-12-05 add: polverine-carrier project directory
    [isd-polverine-carrier.kicad_pcb, isd-polverine-carrier.kicad_sch]
2025-12-05 update: isd-polverine-carrier/sch (add battery protection circuit)
    [isd-polverine-carrier.kicad_sch]
2025-12-07 Added first charger controller prototype
    [battery.kicad_sch, isd-polverine-carrier.kicad_sch]
2026-01-07 update: battery protection circuit (assign components, change to hand-solderable footprints)
    [isd-polverine-carrier.kicad_sch]
2026-01-07 add: LDO (3V3)
    [isd-polverine-carrier.kicad_sch]
2026-01-07 add: PV charger (simple, hand-solderable)
    [isd-polverine-carrier.kicad_sch]
2026-01-07 add: Polverine mikroBUS headers
    [isd-polverine-carrier.kicad_sch]
2026-01-08 add: USB-port for charging, carrier headers, battery monitoring
    [isd-polverine-carrier.kicad_sch]
2026-01-13 Added P Mos to solar charger controller for load sharing
    [battery.kicad_sch, isd-polverine-carrier.kicad_sch]
2026-01-19 add: isd-board (DFR1117 version, non-MPTT)
    [isd-board_dfr1117.kicad_pcb, isd-board_dfr1117.kicad_sch]
2026-01-19 add: isd-board_polverine (MPTT version base)
    [isd-board_polverine.kicad_pcb, isd-board_polverine.kicad_sch]
2026-01-19 update: battery protection circuit (compact placement)
    [isd-board_dfr1117.kicad_pcb, isd-board_dfr1117.kicad_sch, isd-board_polverine.kicad_pcb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]
2026-01-28 update: dual-socket sch/pcb (polverine socket, dfr1117 socket, grove-conn, zif-conn (bmv080), lga 3x3mm (bme690), b5b-zr (sps30))
    [isd-board_polverine.kicad_pcb, isd-board_polverine.kicad_sch]
2026-01-28 update: README.md (to reflect current project goals)
2026-01-29 Added resistor values to MPPT and connection to Battery protection
    [isd-board_polverine.kicad_sch, mppt_battery.kicad_sch]
2026-02-04 lora power gate initial commit
    [lora_pwgate.kicad_sch]
2026-02-05 update: sch/pcb (pin routing, bmv690/bmv080 footprints, power switch ic)
    [isd-board_polverine.kicad_pcb, isd-board_polverine.kicad_sch]
2026-02-15 New Schematic with complete Power Supply
    [isd-board_polverine.kicad_pcb, isd-board_polverine.kicad_sch, mppt_battery.kicad_sch]
2026-02-15 added bill of materials with mouser number parts
    [isd-board_polverine.xlsx]
2026-02-16 Here the latest complete Version including PCB Design
    [isd-board_polverine.csv, isd-board_polverine.kicad_pcb, isd-board_polverine.kicad_sch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]
